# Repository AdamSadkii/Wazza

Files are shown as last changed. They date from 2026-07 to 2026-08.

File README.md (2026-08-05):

# Wazza - Magic in The Air

Wazza is a fully open-source, gesture-controlled AI wand that translates physical hand motions into real-time digital commands. By tracking movement via an internal MPU-6050 6-axis IMU, the onboard ESP32-S3 Mini microcontroller processes gesture vectors, coordinates peripheral systems, and streams telemetry data to an onboard OLED screen alongside audio feedback through an integrated I2S speaker interface.

## Key Features

- 1 x ESP32-S3-MINI-1 Microcontroller (Main Brain)
- 1 x MPU-6050 6-Axis Motion Sensor (IMU)
- 1 x MAX98357A I2S Audio Amplifier & 2W Speaker
- 1 x SPH0645 I2S MEMS Microphone
- 1 x 18650 LiPo Battery Cell
- 1 x TP4056 USB-C Battery Charger Module
- 1 x Tactile Push Button (Momentary switch)
- 1 x WS2812B RGB LED Strip (15-20 LEDs)
- 10 x Resistors (For the required I2C data/clock pull-ups)
- 3 x Electrolytic Capacitors

## How to get the code (not on Vercel)

This is not hosted on Vercel. You grab it from GitHub and run it on your PC.

1. Go to https://github.com/AdamSadkii/Wazza
2. Hit the green Code button
3. Click Download ZIP (or clone it if you use git)
4. Unzip it
5. Open the folder in VS Code / Cursor (or open `Wazza.code-workspace`)

Folders you care about:
- `frontend/` = dashboard
- `backend/` = python server + AI
- `firmware/` = ESP32 code

## Run it on your PC

1. Open a terminal in `backend`
2. Make a venv: `python -m venv .venv`
3. Activate it: `.\.venv\Scripts\Activate.ps1`
4. Install deps: `pip install -r requirements.txt`
5. Run it: `python server.py`
6. Open http://localhost:8000 in your browser

Optional AI:
- set `OPENAI_API_KEY` or run Ollama locally

## Flash the wand

1. Copy `firmware/src/secrets.example.h` to `firmware/src/secrets.h`
2. Put your wifi name/password in there
3. Put your PC IP in `BACKEND_HOST` (port 8765)
4. Open `firmware/` in PlatformIO
5. Build + upload to the ESP32-S3
6. Keep `python server.py` running so the wand can connect

## Schematic








The schematic composes a well organized layout of each system in the device, ranging from power management to the microcontroller itself. This lays the ideal blueprint for the PCB.

The power system (powered by a USB-C component, is the base component of the whole project. A user plugs in a wire in order to actually connect to the code itself, and allow the Ai to run within itself. That way the user can just prompt using the commanded gestures it follows.

## PCB




## Future Enhancements

Potential improvements include on-device machine learning for gesture recognition to reduce API latency, integration with additional sensors like IMUs or proximity detectors, wireless charging capability, and support for custom gesture training. The modular design allows for easy hardware upgrades without redesigning the entire system.

## Files and Documentation

The project includes complete KiCAD schematic files organized by functional module, PCB layout files for fabrication, Arduino firmware source code with gesture templates, and assembly instructions with wiring diagrams. All code is open source and available for modification and redistribution.

## CADDED Module



## Thank you.
A big thanks to Nesh, Keam, and Yahya for being part of the process the whole way. Without them I don't think I would've been able to make it as far.
deduct 2 hrs

## License: MIT

Copyright 2026

Permission is hereby granted, free of charge, to any person obtaining a copy of this software and associated documentation files (the "Software"), to deal in the Software without restriction, including without limitation the rights to use, copy, modify, merge, publish, distribute, sublicense, and/or sell copies of the Software, and to permit persons to whom the Software is furnished to do so, subject to the following conditions:

The above copyright notice and this permission notice shall be included in all copies or substantial portions of the Software.

THE SOFTWARE IS PROVIDED "AS IS", WITHOUT WARRANTY OF ANY KIND, EXPRESS OR IMPLIED, INCLUDING BUT NOT LIMITED TO THE WARRANTIES OF MERCHANTABILITY, FITNESS FOR A PARTICULAR PURPOSE AND NONINFRINGEMENT. IN NO EVENT SHALL THE AUTHORS OR COPYRIGHT HOLDERS BE LIABLE FOR ANY CLAIM, DAMAGES OR OTHER LIABILITY, WHETHER IN AN ACTION OF CONTRACT, TORT OR OTHERWISE, ARISING FROM, OUT OF OR IN CONNECTION WITH THE SOFTWARE OR THE USE OR OTHER DEALINGS IN THE SOFTWARE.

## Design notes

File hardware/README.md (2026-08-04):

# Wazza hardware

| Path | What |
|---|---|
| `kicad/` | KiCad 10 project (schematics + routed PCB) |
| `cad/Wand3.step` | Enclosure CAD (Onshape / Wand3 export) |
| `gerbers/` | Gerber + Excellon drill (+ `wazza_gerbers.zip`) |
| `wiring/` | Schematic PDF + PCB preview / routed renders |
| `WIRING.md` | Net / pin map |
| `ASSEMBLY.md` | Build and assembly steps |

Open `kicad/wazza.kicad_pro` in **KiCad 10**.

## Quick fab

Upload `gerbers/wazza_gerbers.zip` to JLCPCB / PCBWay (or similar).  
Board outline: **155 × 26 mm**, 2-layer.

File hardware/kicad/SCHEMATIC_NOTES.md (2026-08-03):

# Wazza KiCad schematic notes

## What this is
Reconstructed KiCad 10 project from:
- GitHub journal schematic screenshots (Journalphotos.md)
- BOM.md reference designators
- Final hierarchical sheet labels (SDA/SCL/I2S_*/AMP_DIN/MIC_DOUT)

## Open in KiCad
1. Install KiCad 10
2. File -> Open Project -> `hardware/kicad/wazza.kicad_pro`
3. Open `wazza.kicad_sch`

Sheets are wired like the GitHub journal screenshots: orthogonal wires between parts, power ports on pins, global labels at sheet edges.

## Accuracy limits
GitHub does **not** include original `.kicad_sch` sources. Recreation is from screenshots.

Known conflicts between journal revisions:
- Some sheets show I2C on IO21/IO26, others use different GPIOs
- Audio sheet pin annotations disagree across captures
- Early sheets shorted button logic onto SDA (not copied; buttons are separate nets here)
- OLED numbered U15 in one sheet, BOM says U14
- LED rail shown as +5V in one capture, +3V3 in another

This project uses one consolidated MCU map so the hierarchy ERC can resolve:
- IO4 SCL, IO5 SDA
- IO0 BTN_BOOT, IO8 BTN_ACTION
- IO18 LED_DIN
- IO21 I2S_LRCLK, IO26 I2S_BCLK, IO33 AMP_DIN, IO34 MIC_DOUT

Power sheet topology matches the clear USB-C / MCP73831 / battery / AP2112K screenshot.

## Not included
- Full ESP32-S3-MINI-1 pinout (only used pins modeled)
- Exact PCB footprints for every connector
- Layout (`.kicad_pcb`) - ask if you want that next from screenshots

## Sheets
1. `01_power.kicad_sch`
2. `02_mcu.kicad_sch`
3. `03_sensors.kicad_sch`
4. `04_audio.kicad_sch`
5. `05_leds_buttons.kicad_sch`

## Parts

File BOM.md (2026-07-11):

# Wazza BOM

All parts as placed on the KiCad PCB and Schematic.

## Main Components

- **ESP32-S3-MINI-1-N8** (U9): Wi-Fi + BLE MCU module, main brain. Qty 1. [LCSC](https://www.lcsc.com/product-detail/WiFi-Modules_Espressif-Systems-ESP32-S3-MINI-1-N8_C2913206.html) or [Espressif](https://www.espressif.com/en/module/esp32-s3-mini-1-en)
- **MPU-6050** (U13): 6-axis IMU (accelerometer + gyro) for gesture tracking. Qty 1. [Adafruit](https://www.adafruit.com/product/3886)
- **SSD1306 OLED 0.91"** (U14): 128x32 I2C display. Qty 1. [Adafruit](https://www.adafruit.com/product/931)
- **MAX98357A** (U12): I2S 3W Class-D audio amplifier. Qty 1. [Adafruit](https://www.adafruit.com/product/3006)
- **SPH0645LM4H** (MK2/MK3): I2S MEMS microphone, populate one only. Qty 1. [Adafruit](https://www.adafruit.com/product/3421)
- **MCP73831-2** (U1): LiPo charge controller, SOT-23-5. Qty 1. [Microchip](https://www.microchip.com/en-us/product/mcp73831)
- **AP2112K-3.3** (U2): 3.3V 600mA LDO regulator, SOT-23-5. Qty 1. [Diodes Inc](https://www.diodes.com/part/view/AP2112)
- **WS2812B** (D1): Addressable RGB LED, 5050 package. Qty 1. [DigiKey search](https://www.digikey.com/en/products/result?keywords=WS2812B)
- **WS2812B LED strip** (J2): External addressable strip, 15 to 20 LEDs. Qty 1. [Adafruit NeoPixel strip](https://www.adafruit.com/product/1376)
- **Speaker** (LS1): 8 ohm ~1W mini speaker. Qty 1. [Adafruit](https://www.adafruit.com/product/3968)

## Power & Connectors

- **USB-C receptacle** (J1): USB 2.0 16-pin, TYPE-C-31-M-12. Qty 1. [LCSC](https://www.lcsc.com/product-detail/USB-Connectors_Korean-Hroparts-Elec-TYPE-C-31-M-12_C165948.html)
- **JST-EH 2-pin** (BT1): Battery connector, S2B-EH. Qty 1. [DigiKey search](https://www.digikey.com/en/products/result?keywords=S2B-EH)
- **LiPo battery**: 3.7V single cell. Qty 1. [Adafruit 2000mAh](https://www.adafruit.com/product/328)

## Small Parts

- **Tactile switches** (SW2, SW3): Momentary push buttons for action + boot. Qty 2. [Adafruit 20-pack](https://www.adafruit.com/product/367)
- **Resistors** (R1 to R15): 0805 SMD, I2C pull-ups, CC resistors, PROG set, etc. Qty ~10. [DigiKey 0805 resistors](https://www.digikey.com/en/products/filter/chip-resistor-surface-mount/52)
- **Capacitors** (C1 to C5): Decoupling and bulk caps. Qty 5. [DigiKey MLCC](https://www.digikey.com/en/products/filter/ceramic-capacitors/60)

## Notes

- MK2 and MK3 are the same microphone footprint in two positions, populate one only.
- Resistor and capacitor values are in the KiCad schematic; buy a 0805 assortment kit if unsure.
- The bare WS2812B is on-board; J2 is the header for the external strip in the wand shaft.

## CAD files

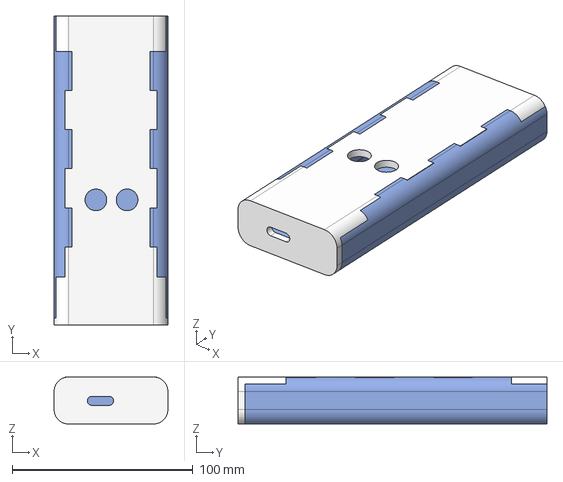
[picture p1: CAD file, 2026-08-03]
hardware/cad/Wand3.step
63.0 x 171.0 x 26.0 mm

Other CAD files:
Wand3 STEP file (1).step

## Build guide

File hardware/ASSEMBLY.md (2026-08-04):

# Wazza assembly instructions

## What you need

- Fabricated PCB from `hardware/gerbers/` (JLCPCB / PCBWay / similar) — use `wazza_gerbers.zip`
- Enclosure STEP: `hardware/cad/Wand3.step`
- Parts from the project BOM / schematic
- USB-C cable, LiPo cell, 8 Ω speaker, NeoPixel strip (optional)

## Board fit

PCB outline is **155 mm × 26 mm** (rounded ends), sized to fit the Wand3 STEP mid-cavity (~51 × 169 mm usable) with wall clearance.  
Confirm fit in CAD before ordering a large panel.

## Before you order (KiCad checklist)

1. Open `kicad/wazza.kicad_pro` and run **DRC**.  
2. Finish remaining ratsnest if any (typically **SDA** and a small **U12-OUTP** stitch).  
3. Refill zones (GND / +3V3 / battery pours).  
4. Re-export Gerbers if you changed copper.

## Solder order

1. SOT-23-5 parts U1 (MCP73831) and U2 (AP2112K-3.3)  
2. 0805 passives (R1–R3, R10, R13–R15, C1, C3, C4)  
3. QFN amp U12 (MAX98357A) and IMU U13  
4. WS2812B (D1)  
5. Buttons SW2 / SW3  
6. USB-C receptacle J1  
7. ESP32-S3-WROOM-1 module U9 (antenna keepout — no metal under antenna)  
8. Headers: battery BT1, OLED U14, speaker LS1, mic MK2, LED strip J2  

## First power-up

1. No battery yet. USB-C only.  
2. Check +3V3 to GND is about 3.3 V.  
3. Confirm no shorts on VBUS / VBAT / +3V3.  
4. Flash firmware (`firmware/`, PlatformIO env `wazza_s3`).  
5. Connect battery only after the 3.3 V rail looks good.

## Enclosure

1. Import `hardware/cad/Wand3.step` into your CAD tool.  
2. Seat PCB in the pocket with USB-C at the handle opening.  
3. Route speaker / mic / LED strip wires toward the tip cavity.  
4. Close shell; keep the antenna end clear of metal.

## Wiring reference

- Pin map: `hardware/WIRING.md`  
- Schematic PDF: `hardware/wiring/wazza_schematic.pdf`  
- PCB renders: `hardware/wiring/pcb_preview.png`, `pcb_routed.png`

## Accuracy note

Journal PCB screenshots were the visual reference; this KiCad board recreates that placement and STEP fit, then autoroutes copper. Treat the first fab spin as a prototype and verify DRC in KiCad first.

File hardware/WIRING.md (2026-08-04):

# Wazza hardware wiring

Source of truth for nets: KiCad schematics in `hardware/kicad/`.
PDF export: `hardware/wiring/wazza_schematic.pdf`.

## Consolidated MCU map (matches firmware)

| Net | ESP32-S3 pin | Goes to |
|-----|---|---|
| SCL | IO4 | MPU-6050, OLED, 4.7k pull-up to +3V3 |
| SDA | IO5 | MPU-6050, OLED, 4.7k pull-up to +3V3 |
| BTN_BOOT | IO0 | SW3 to GND, 10k pull-up to +3V3 |
| BTN_ACTION | IO8 | SW2 to GND, 10k pull-up to +3V3 |
| LED_DIN | IO18 | WS2812B DIN, then DOUT to strip header J2 |
| I2S_LRCLK | IO21 | MAX98357A LRCLK, mic WS |
| I2S_BCLK | IO26 | MAX98357A BCLK, mic BCLK |
| AMP_DIN | IO33 | MAX98357A DIN |
| MIC_DOUT | IO34 | SPH0645 DATA |
| +3V3 / GND | module rails | all ICs |

## Power path

USB-C VBUS -> MCP73831 -> VBAT / LiPo -> AP2112K-3.3 -> +3V3  
CC1/CC2 each have 5.1k to GND. PROG uses 2k to GND.

## Sheet map

1. `01_power` – USB-C, charger, battery, 3.3V LDO  
2. `02_mcu` – ESP32-S3 module + GPIO globals  
3. `03_sensors` – MPU-6050 + OLED + I2C pull-ups  
4. `04_audio` – MAX98357A + mic + speaker  
5. `05_leds_buttons` – WS2812B, strip header, buttons  

## Fabrication outputs

Gerbers + drill: `hardware/gerbers/` (zip: `wazza_gerbers.zip`)  
PCB preview: `hardware/wiring/pcb_preview.png`  
Routed render: `hardware/wiring/pcb_routed.png`

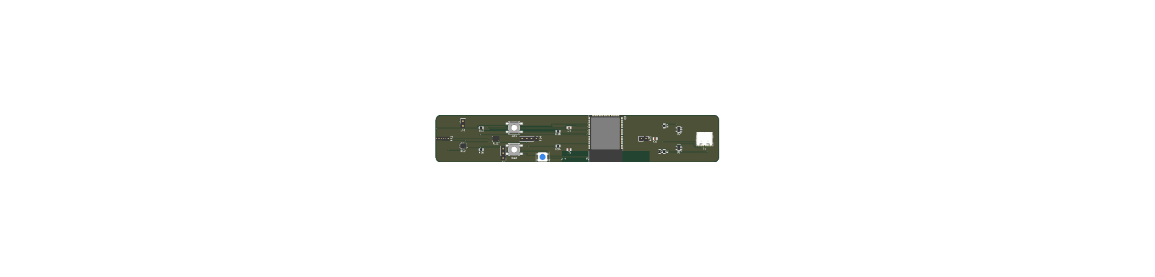
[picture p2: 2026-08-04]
hardware/wiring/pcb_routed.png

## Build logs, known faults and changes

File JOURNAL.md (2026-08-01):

# JOURNAL

## Schematic Complete - Day 6/28/26 (5h58min)

### Overview
Finally finished the schematic. Coming into this schematic, I knew I wanted to focus on one thing: the microcontroller as the main component. However, in hopes of organization, I thought otherwise and considered splitting things up.

### Design Decisions

At first, I originally wanted to split my schematic into different pages, each serving their own purpose. I planned one page for the sensor interface, another for the audio interface, and so on and so forth. However, due to redundancy (I tried to add a connections page combining everything) and time constraints, I realized the easier pathway led to one single schematic instead.

### Architecture

The basis of my schematic focuses on, as said before, my microcontroller: the ESP32. The ESP32 served as the central component of my project, with everything else orbiting around it:

* **ESP32**: The brain of the operation, handling all processing and coordination
* **OLED Display**: Provides the user with basic info and feedback
* **MPU-6050**: Tracks the user's gestures and movements (literally one of the most important parts of my wand LOL)
* **Supporting Components**: Battery management, audio I/O, LED control, all centralized around the microcontroller

### What I Learned

Keeping everything on a single page actually made more sense than I initially thought. The redundancy of multiple connection pages would have just added complexity without clarity. Sometimes simpler is better, and this schematic proves that point.

### Next Steps

Tomorrow, I will get to the PCB and hopefully get most of it done. Although it's an impending doom, I am really excited to work on that aspect of my project. The schematic is solid, so the layout should flow naturally from here.

### Reflection

This feels like a major milestone. The schematic is the blueprint for everything that comes next. Seeing all the connections laid out clearly gives me confidence that the hardware design is sound. Time to bring it to life on the PCB.

---

## Organizing PCB - Day 6/29/26 (Hour 1) **[LAPSED DAY]**

I am organizing the PCB. Currently splitting each component on its own but we're figuring it out. Even though the components are a little hard to figure out, it's totally okay. 



---

## Schematic Fix - Day 6/29/26 (Hours 2-3) **[LAPSED DAY]**

I discovered a major error on the PCB layout where resistors R4 and R5 were both connected directly to the 3.3V line, which would have broken the communication loop. After two hours of troubleshooting, I corrected the wiring paths and utilized several pins that were previously ignored. This process exposed a widespread series of errors throughout the schematic, requiring another two hours of focused adjustments. While the rework was incredibly tedious, tracking down and correcting those design flaws was deeply rewarding.





---

## Journal Day 6/29/26 - PCB Almost Done? (Hours: 3) **[LAPSED DAY]**

PCB Layout Started - Day 6/30/26 **[LAPSED DAY]**

### Overview

Today was incredibly productive yet absolutely exhausting. I took the massive leap into creating my first-ever physical PCB layout. Moving from the abstract schematic canvas to actual component footprints makes the wand feel real, though it definitely brought some brutal troubleshooting with it.

### Design Decisions & Troubleshooting

I hit a major roadblock early on regarding the OLED screen and the IMU pull-up resistors. During my initial layout check, I realized my wiring accidentally tied both sides of $R4$ and $R5$ directly to the +3.3V line, completely missing the actual SCL and SDA lines. Instead of moving forward with a broken bus, I paused and forced myself to rewire those schematic components properly. It took a couple of hours of careful tracing, but I finally re-run the check successfully. Once the schematic was cleared, I imported it into the PCB editor and successfully modeled the initial physical flow of the wand stretching all the way from the USB-C port to the OLED screen placement.

### Architecture

As the layout began coming together, the physical constraints forced me to re-evaluate my component choices:

* **ESP32 Module**: Looking at the footprint placement, I realized I might have utilized the wrong specific module variant. Thankfully, it's not a catastrophic fix; I just need to swap the symbol/footprint and re-designate the pins to match my existing wiring routing.
* **Net Labels**: Moving forward, I need to heavily integrate net labels rather than drawing raw local wires. It will make updating the schematic and updating the PCB track layout infinitely smoother.

### What I Learned

Catching a massive I2C pull-up mistake now instead of after fabrication taught me why electrical checks are so critical. A few hours of frustration today saved weeks of waiting on a broken, un-fixable board later.

### Next Steps

Tomorrow is all about fixing that ESP32 module variant, cleaning up the routing, and finalizing the board outline. There is still a bit of uncertainty about the tight layout, but the goal is to get the CAD fully submitted so we can ship the design files out for manufacturing. Job's not finished; let's get this accepted.




---

## Schematic Rewire WE ALMOST DONE - Day 6/30/26 (Hours 1-2) **[LAPSED DAY]**

Decided to rewire my schematic as I realized I was using the Chip version of the ESP32-S3 and not the actual module version (I chose the ESP32-S3 Mini). Both my sensor interface and power management is done. 




---

## Schematic Rewire So close - Day 6/30/26 (Hours 3-4) **[LAPSED DAY]**

I decided for a neater version so I resorted to different page sheets and made it simpler. This solved my rewiring issue entirely and made it much more simpler. Additionally, I resorted to the ESP32-S3 Mini and was able to complete a successful rewire towards the microcontroller connecting everything at once. 





---

## Schematic Rewire - Day 6/30/26 (Hours 4-5) **[LAPSED DAY]**

To end the Schematic Rewire (finally..) I finished my OLED and Audio Interface, two important components connecting to my ESP32. The OLED will display info and will later be programmed to do so, meanwhile the Audio Interface will do the same in an audio format. 




---

## Day 6/30/26 (4hrs 48 min) **[LAPSED DAY]**

### Devlog â€“ June 30, 2026

**Focus:** Complete Schematic Overhaul, Hierarchical Sheets, & Peripheral Integration

Massive milestone hit today. Realized a fundamental mismatch in the central microcontroller component selection and completely overhauled the schematic architecture to transition from a messy, single-page layout to a clean, production-ready multi-sheet design.

#### Accomplishments:

* **Microcontroller Core Correction (Hours 1â€“2):**
  * Identified a critical error: the schematic originally used the raw ESP32-S3 IC (chip-down) instead of the actual integrated module (**ESP32-S3-MINI-1**).
  * Swapped out the component block, completely saving the project from massive PCB routing headaches later, as the mini module integrates the flash, RAM, and antenna circuitry automatically.
  * Verified that the completed Sensor Interface and Power Management blocks survived the migration.

* **Hierarchical Page Sheet Migration (Hours 3â€“4):**
  * To solve the escalating "spaghetti wire" mess, abandoned the single-page layout and refactored the entire project into individual hierarchical page sheets.
  * This modular approach completely cleared up the wiring bottlenecks and allowed for a seamless, successful master rewire back to the new ESP32-S3 Mini block using clean global labels.

* **OLED & Audio Interface Integration (Hours 4â€“5):**
  * Finalized the schematic wiring for the dual feedback systems: the visual **OLED Display** block and the **I2S Audio Interface** block.
  * Mapped out the display paths to handle future telemetry data readouts and stabilized the I2S audio channels (microphone input and amplifier output) to provide clean audio feedback down the line.

#### Project Status 6/30/26:

The schematic is officially **100% complete** and fully modularized. Every subsystem, Power, Sensors, OLED, Audio, and LEDs, is cleanly tied back to the ESP32-S3 Mini. Ready to lock it in and move to footprints.




---

## PCB Organized - Time to Reroute! 7/3/26: (1-2 Hours)

The PCB is finally organized, it's time to reroute and make sure the chip is well done and suited. CADDING IS VERY SOON.



---

## Routing... 7/3/26 (2-3 hour)

It's taking a while but we're getting there. I am currently routing everything, PCB will be done by tonight.




---

## Project Development Log: Routing Phase Completion Date: 7/4/26 (5 hours)

I have successfully completed the routing phase for the entire printed circuit board layout. Managing the trace routing presented several structural challenges, particularly regarding the speaker interface strategy and component placement constraints. 

Despite these spatial complexities, all nets have been fully routed, and the connection matrix is complete. The board layout is clean, and the netlist is fully satisfied with zero remaining unrouted connections. The immediate next steps include performing a comprehensive Design Rule Check to verify electrical clearances, optimizing the silkscreen component designators for legibility, and generating the final copper ground pours. 

Once these verification steps are complete, the project will move into the manufacturing file generation phase.



---

## Routing Complete! 7/7 (Hours 1-2) 

Completed routing after reassembling 3 days ago. I was able to reroute everything with the correct net labels finally.





ENJOY WE MAKING HOLES NOW.

---

## Holes Complete, onto CADDING! 7/7 (Hours 2-3)

Holes are officially done, time to move straight onto CADDING.



---

## CADDING... 7/7 (Hour 3)

WE are currently sketching and beginning our first steps into cadding the wand. Lets go.

 

---

## EVERYTHING DONE LETS GOOOOOOOOOO OMG 7/7 (Hours 3-4)

We finished the PCB Routing, we finished the designs, we finished the cadding. WE DID IT (lebron quote.. or jayson tatum? idk but we are completely done). 



---

## Day 7/7/26 (Hours 3-4)

### Devlog â€“ July 7, 2026

**Focus:** Final Routing Validation, Board Mounting Holes, & Structural CAD Completion

Massive milestone hit today. Everything is officially wrapped up from the physical board connections to the outer wand enclosure design. The full system is fully modeled and ready for production file generation.

#### Accomplishments:

* **PCB Routing Validation:**
  * Cleaned up and verified 100% of the trace connections across the board layout, matching everything perfectly with the new net labels on the ESP32-S3 Mini.
  * Completed the full connection matrix with zero remaining unrouted nets or trace bottlenecks.

* **Physical Mounting Holes:**
  * Added the structural mounting drill holes directly onto the finalized PCB outline.
  * Verified all hardware component clearances around the holes to ensure secure physical assembly inside the wand body without risking any trace shorts.

* **3D CAD Assembly:**
  * Transitioned straight from the completed board layout into sketching and cadding the final physical wand body.
  * Successfully matched all component layout configurations, display cutouts, and physical boundary constraints to complete the initial enclosure assembly sketch.

## Day 7/31/26 (Hours 16-17) (LAPSED ON TEAANHACKCLUB@gmail.com USER)

Currently lapsing my email, Currently working on the server.py to handle all of the Wand's messages to the user.



#### Project Status 7/31/26:

The physical layout and hardware configuration phase is **100% complete**. The schematic wiring sheets, PCB routing networks, structural mounting layouts, and external CAD design frames are all fully locked in. Ready to export manufacturing assets and ship it.

---

### Note on Lapsed Days

Days 6/29/26 and 6/30/26 were lapsed for a combined 6hr 17min. These entries are logged above as they were originally recorded. These hours were tracked on my other user --> (teaangoat@gmail.com) the rest of the Hackatime hours are tracked on (teaanhackclub@gmail.com) combining together to make up the total 20 hrs expected by the July 31st deadline.

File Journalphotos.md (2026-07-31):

## Hour 1 6/29/2026


## Hours 2-3 6/29/2026






## Hours 1-2 6/30/2026



## Hours 3-4 6/30/2026




## Hours 4-5 6/30/2026



## Hours 1-2 7/3/2026


## Hours 2-3 7/3/2026



## Hours 1-2 7/7/2026




## Hours 2-3 7/7/2026



## Hours 3-4 7/7/2026


## Hours 16-17 7/31/2026


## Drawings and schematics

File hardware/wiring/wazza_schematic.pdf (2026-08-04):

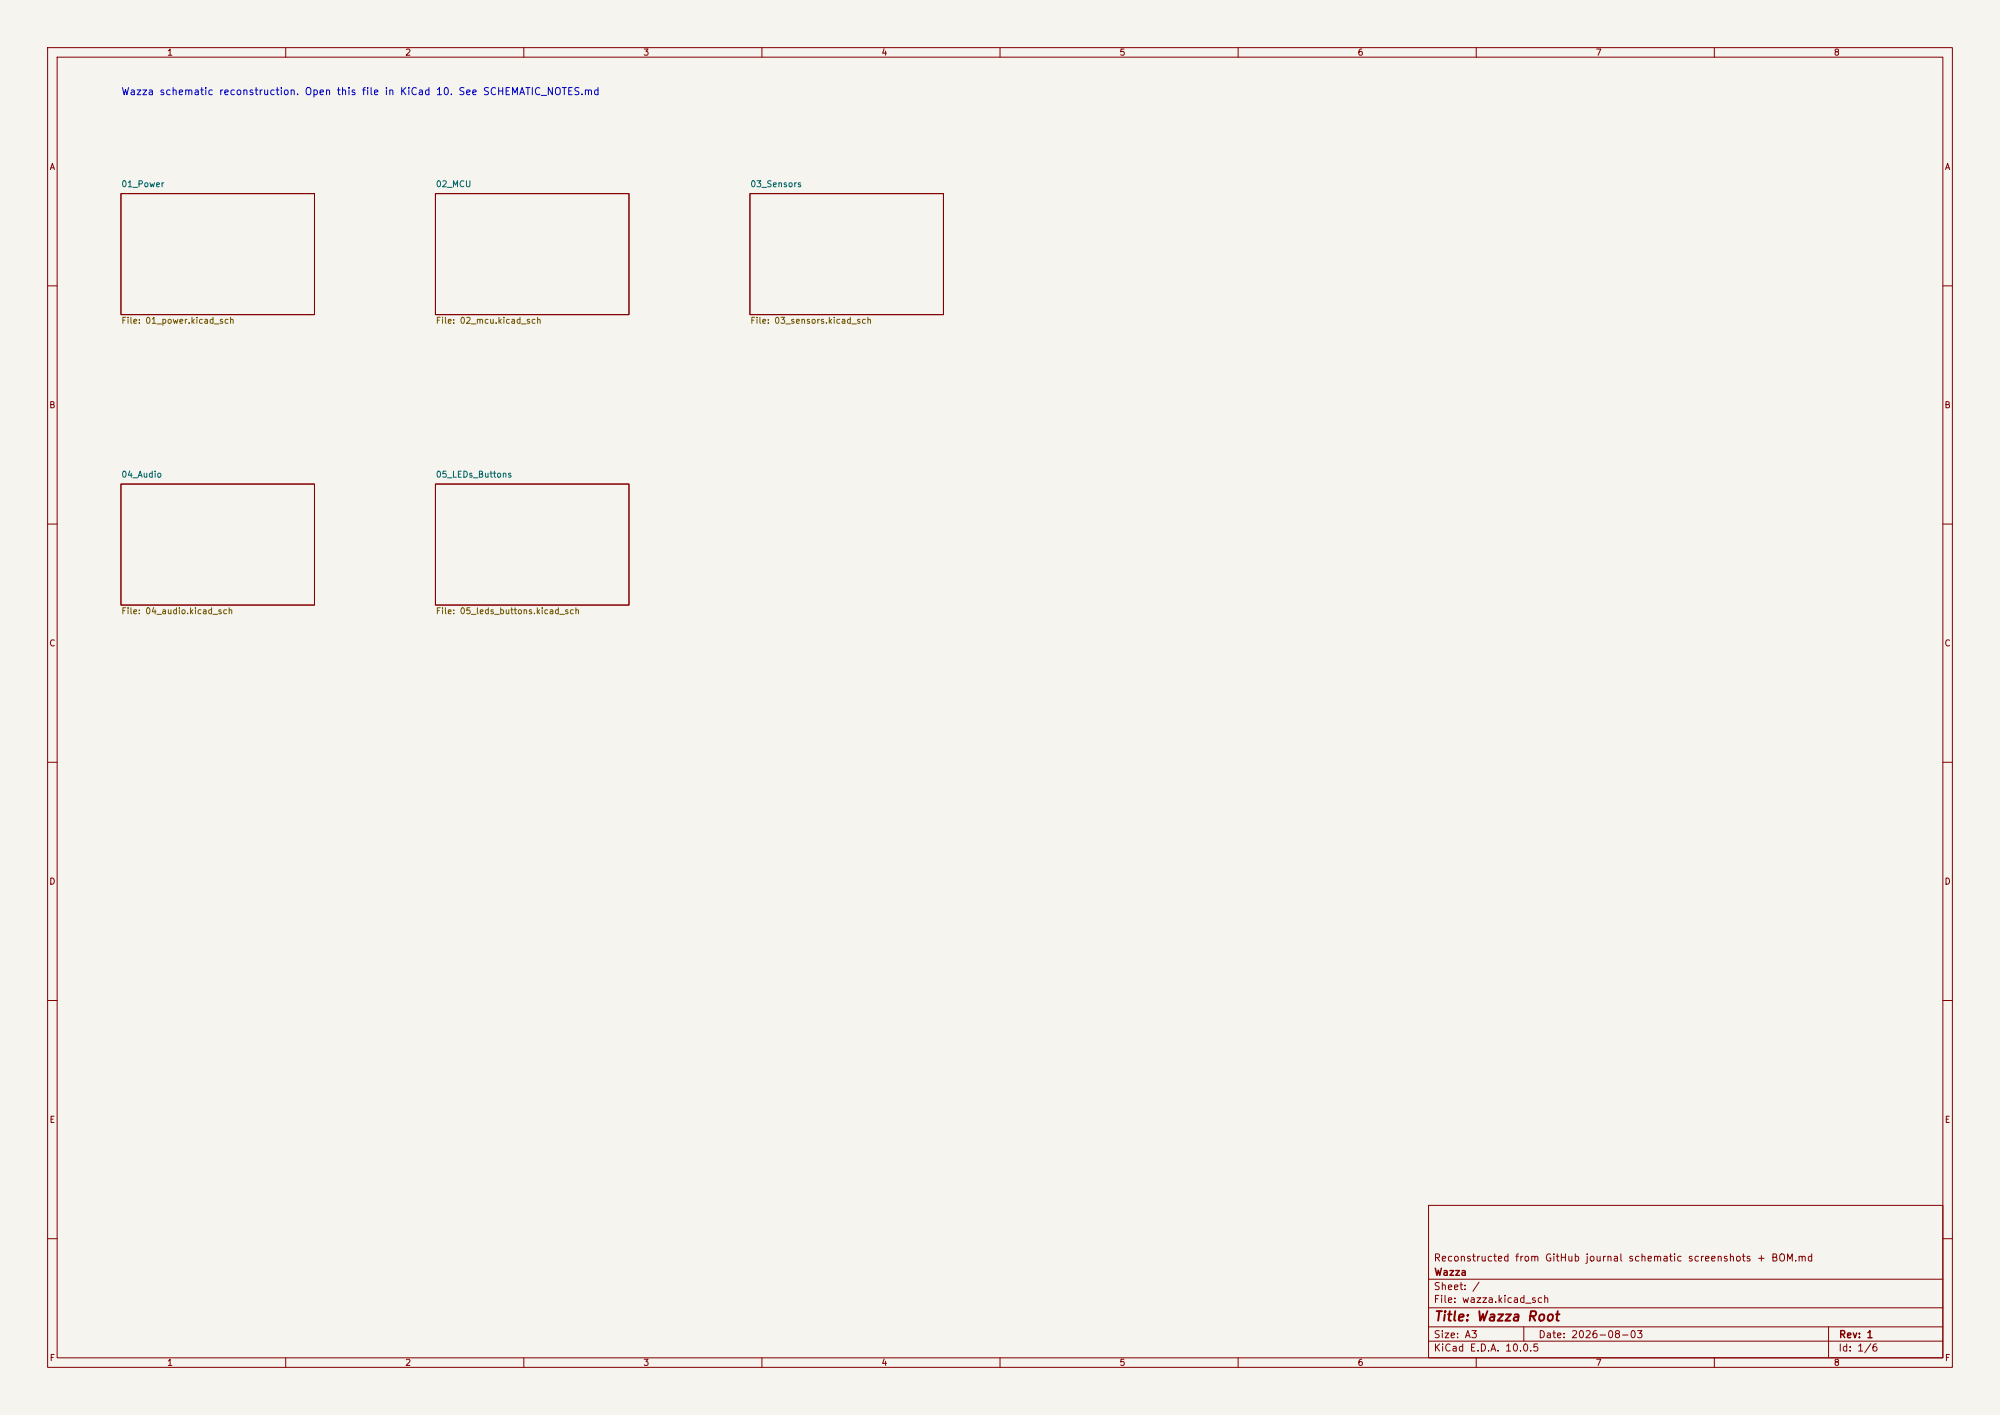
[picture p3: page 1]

File: 02_mcu.kicad_sch Wazza schematic reconstruction. Open this file in KiCad 10. See SCHEMATIC_NOTES.md

Reconstructed from GitHub journal schematic screenshots + BOM.md
Wazza
Sheet: /
File: wazza.kicad_sch
Title: Wazza Root

Size: A3 | Rev: 1 | F Date: 2026-08-03
KiCad E.D.A. 10.0.5 | Id: 1/6

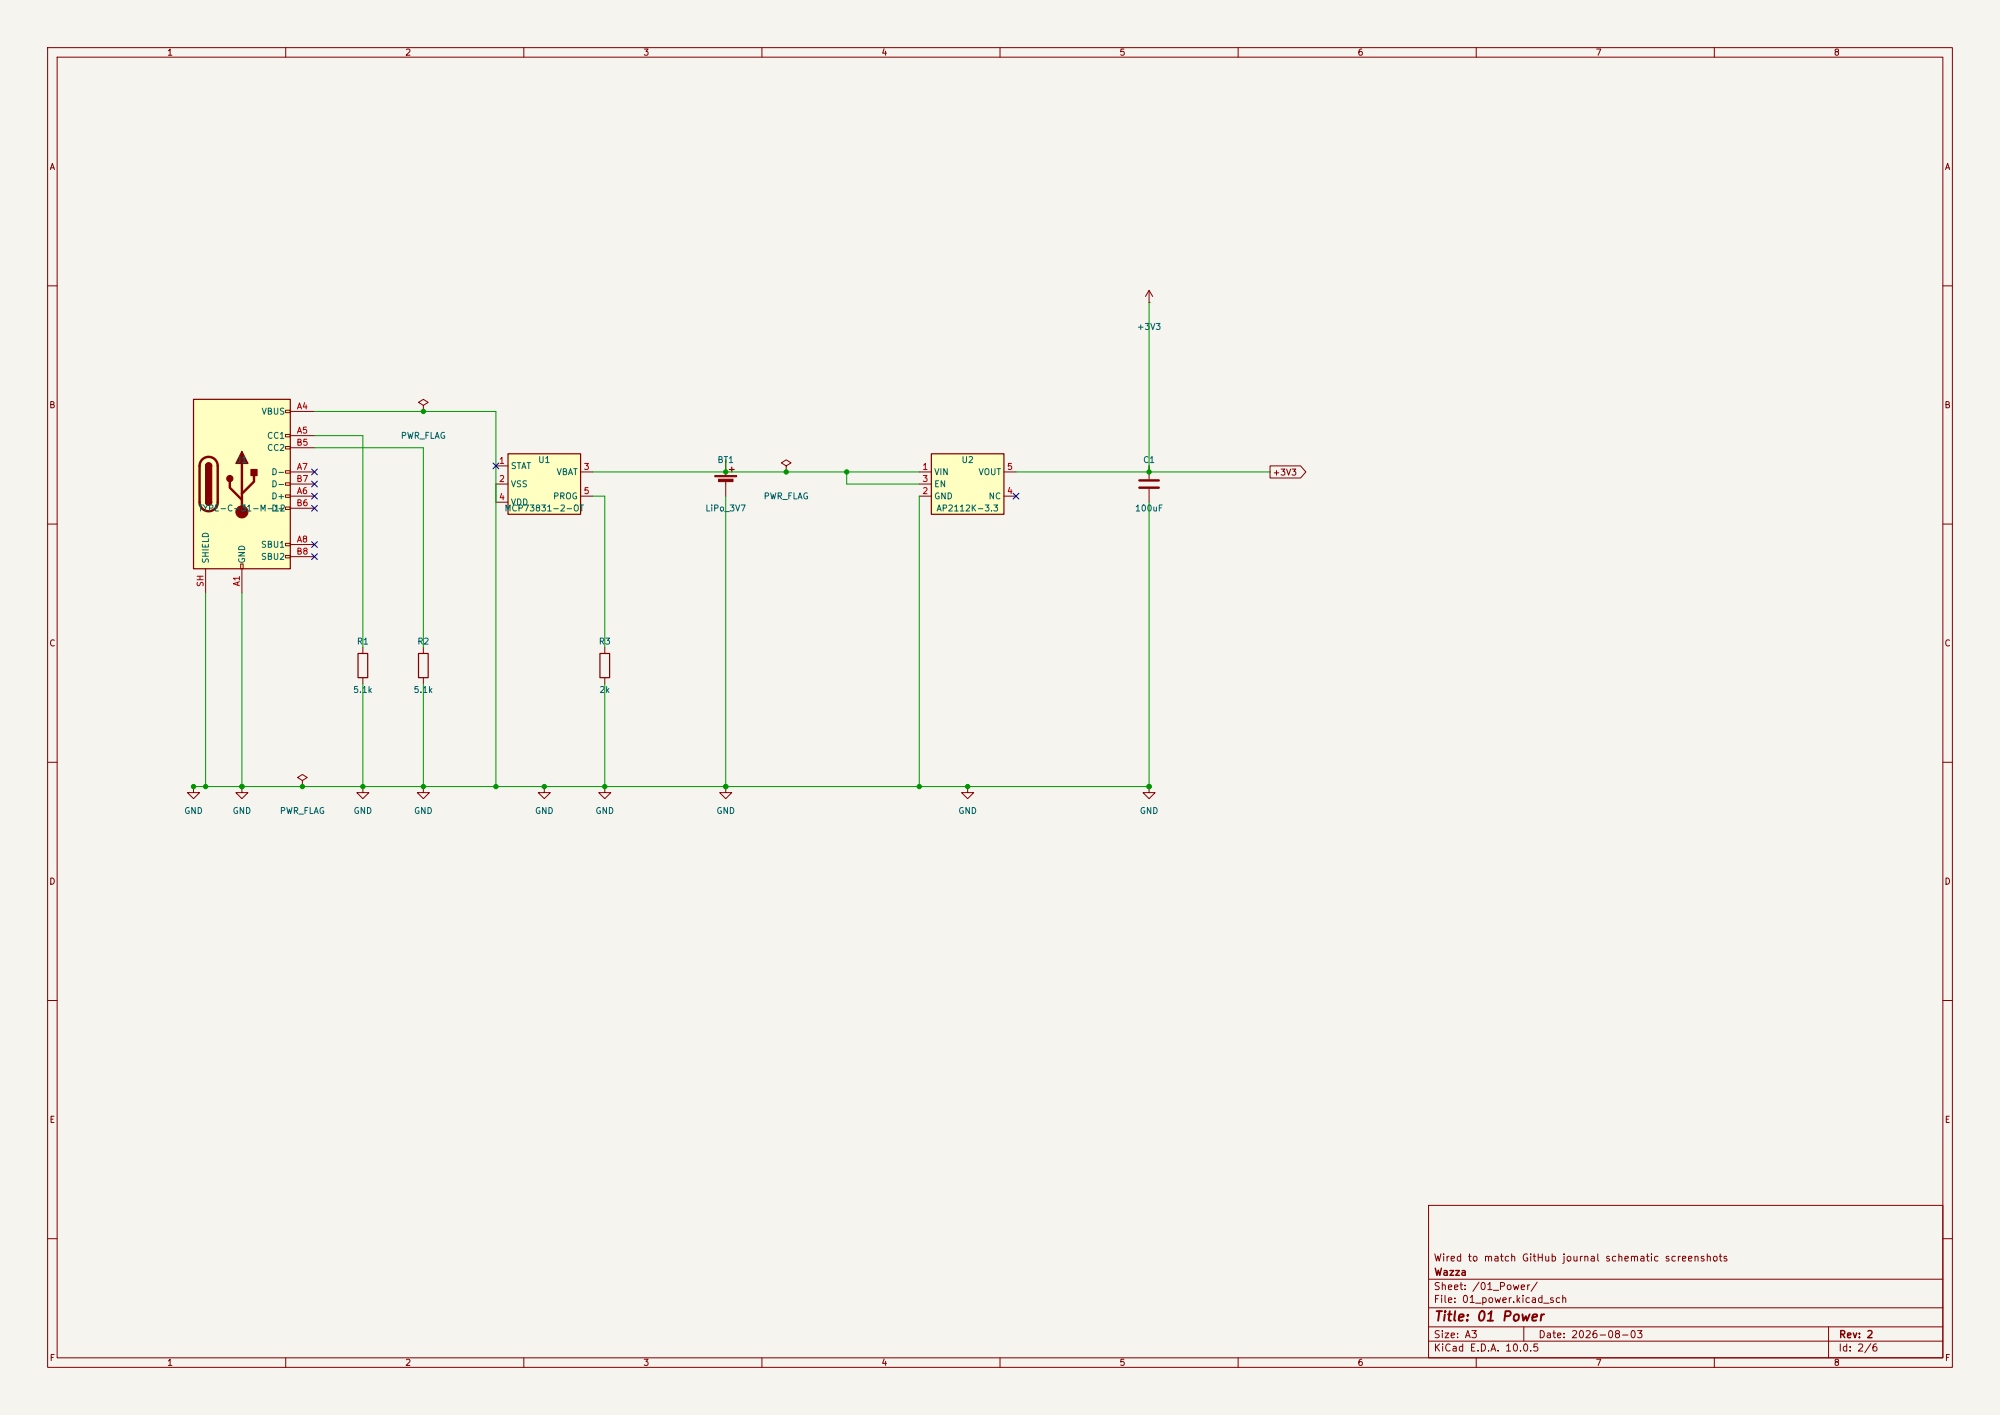
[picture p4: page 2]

Wired to match GitHub journal schematic screenshots
Wazza
Sheet: /01_Power/
File: 01_power.kicad_sch
Title: 01 Power

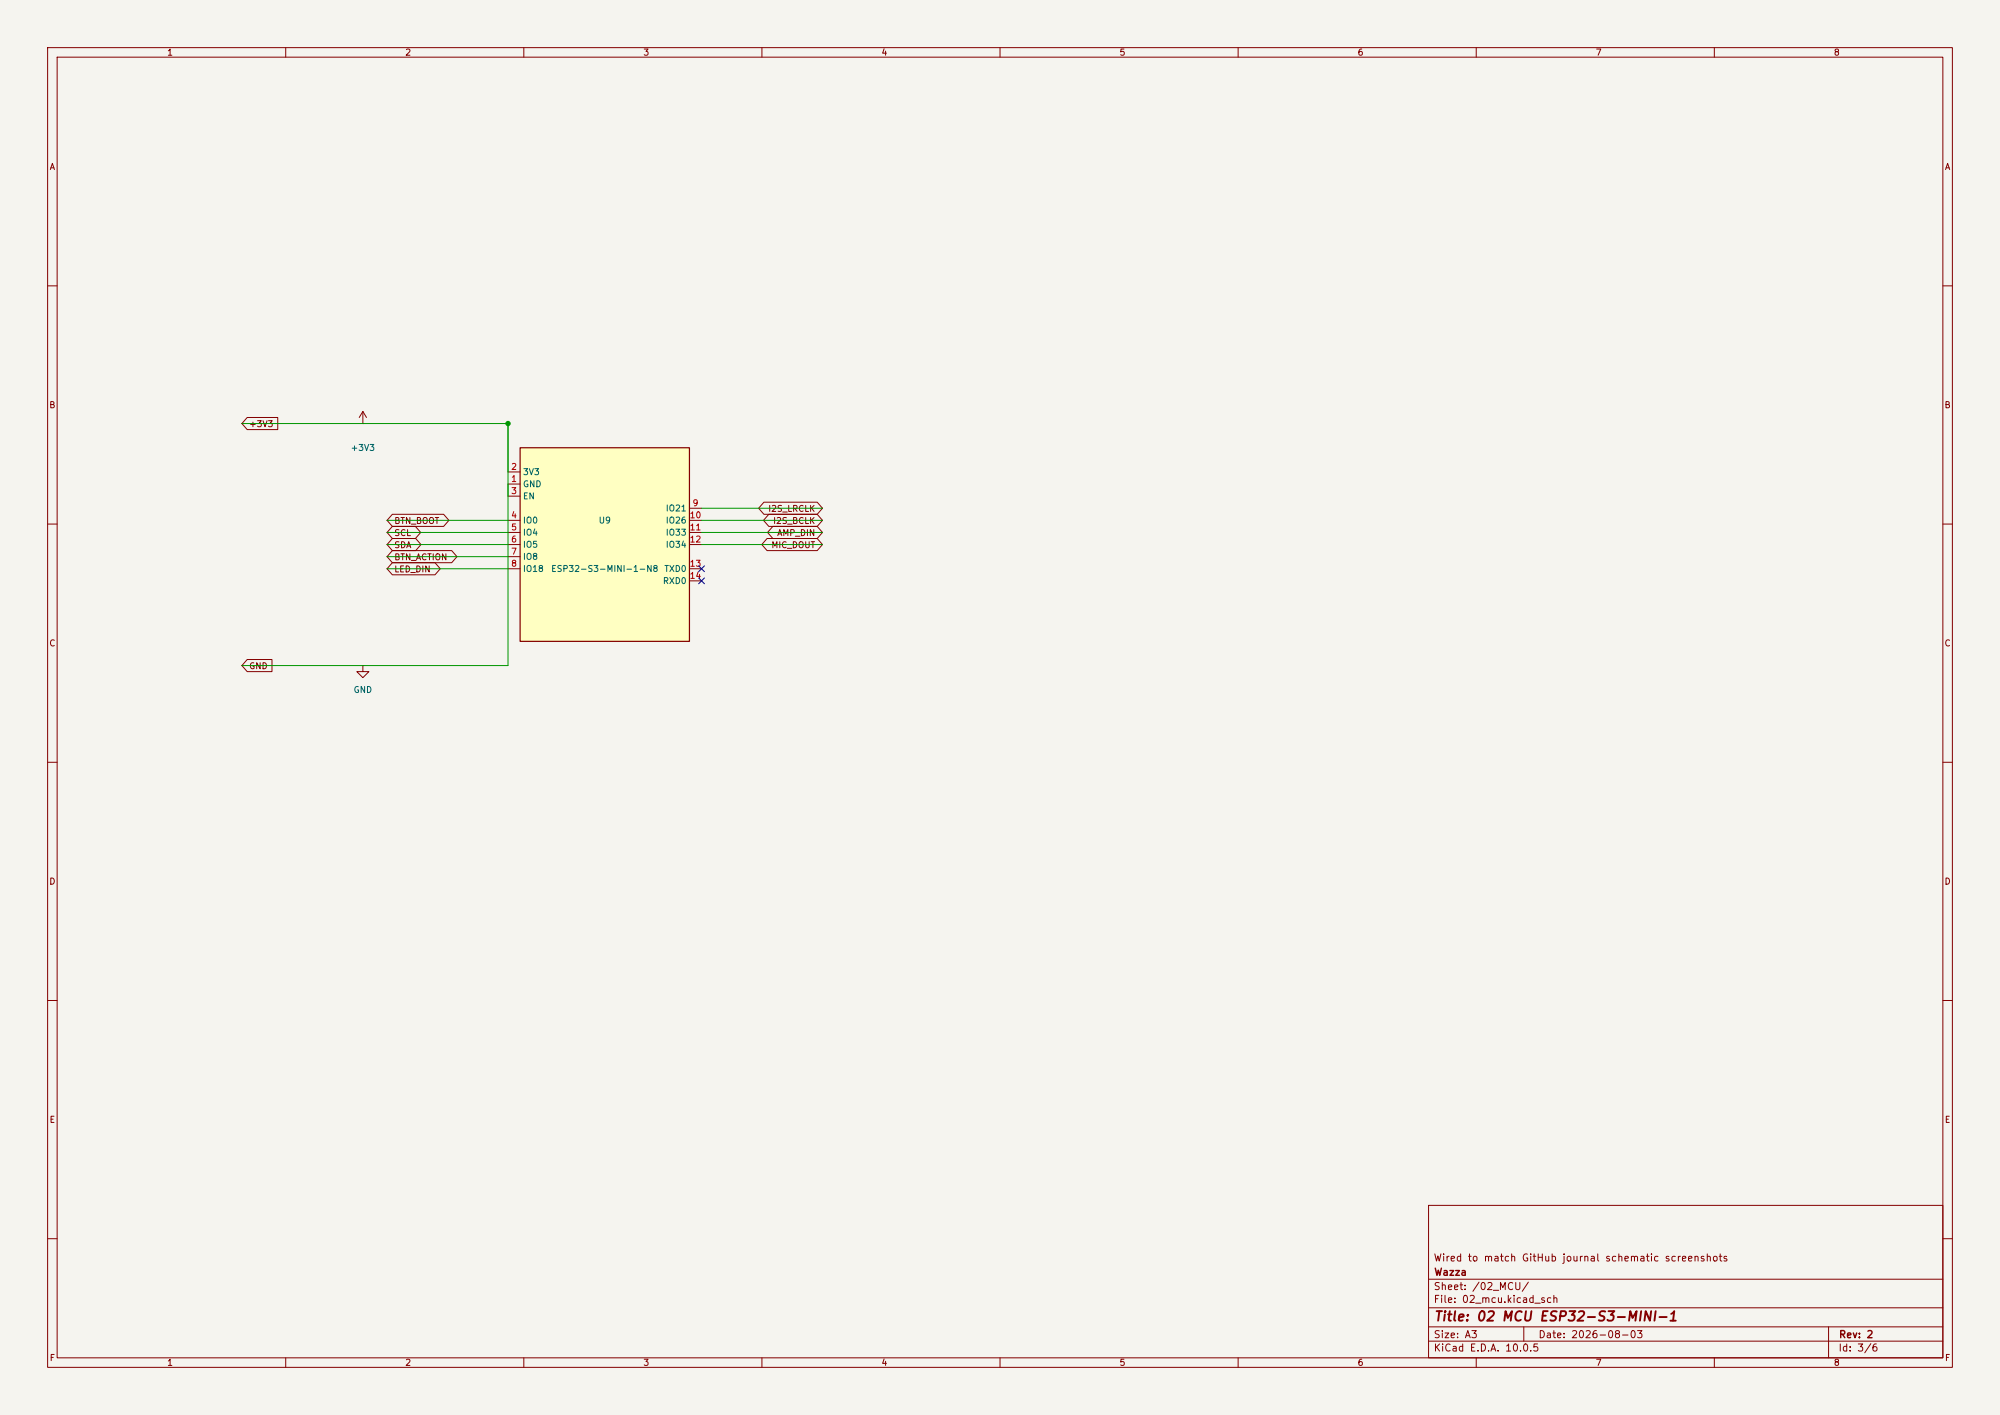
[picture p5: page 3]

Wired to match GitHub journal schematic screenshots
Wazza
Sheet: /02_MCU/
File: 02_mcu.kicad_sch
Title: 02 MCU ESP32-S3-MINI-1

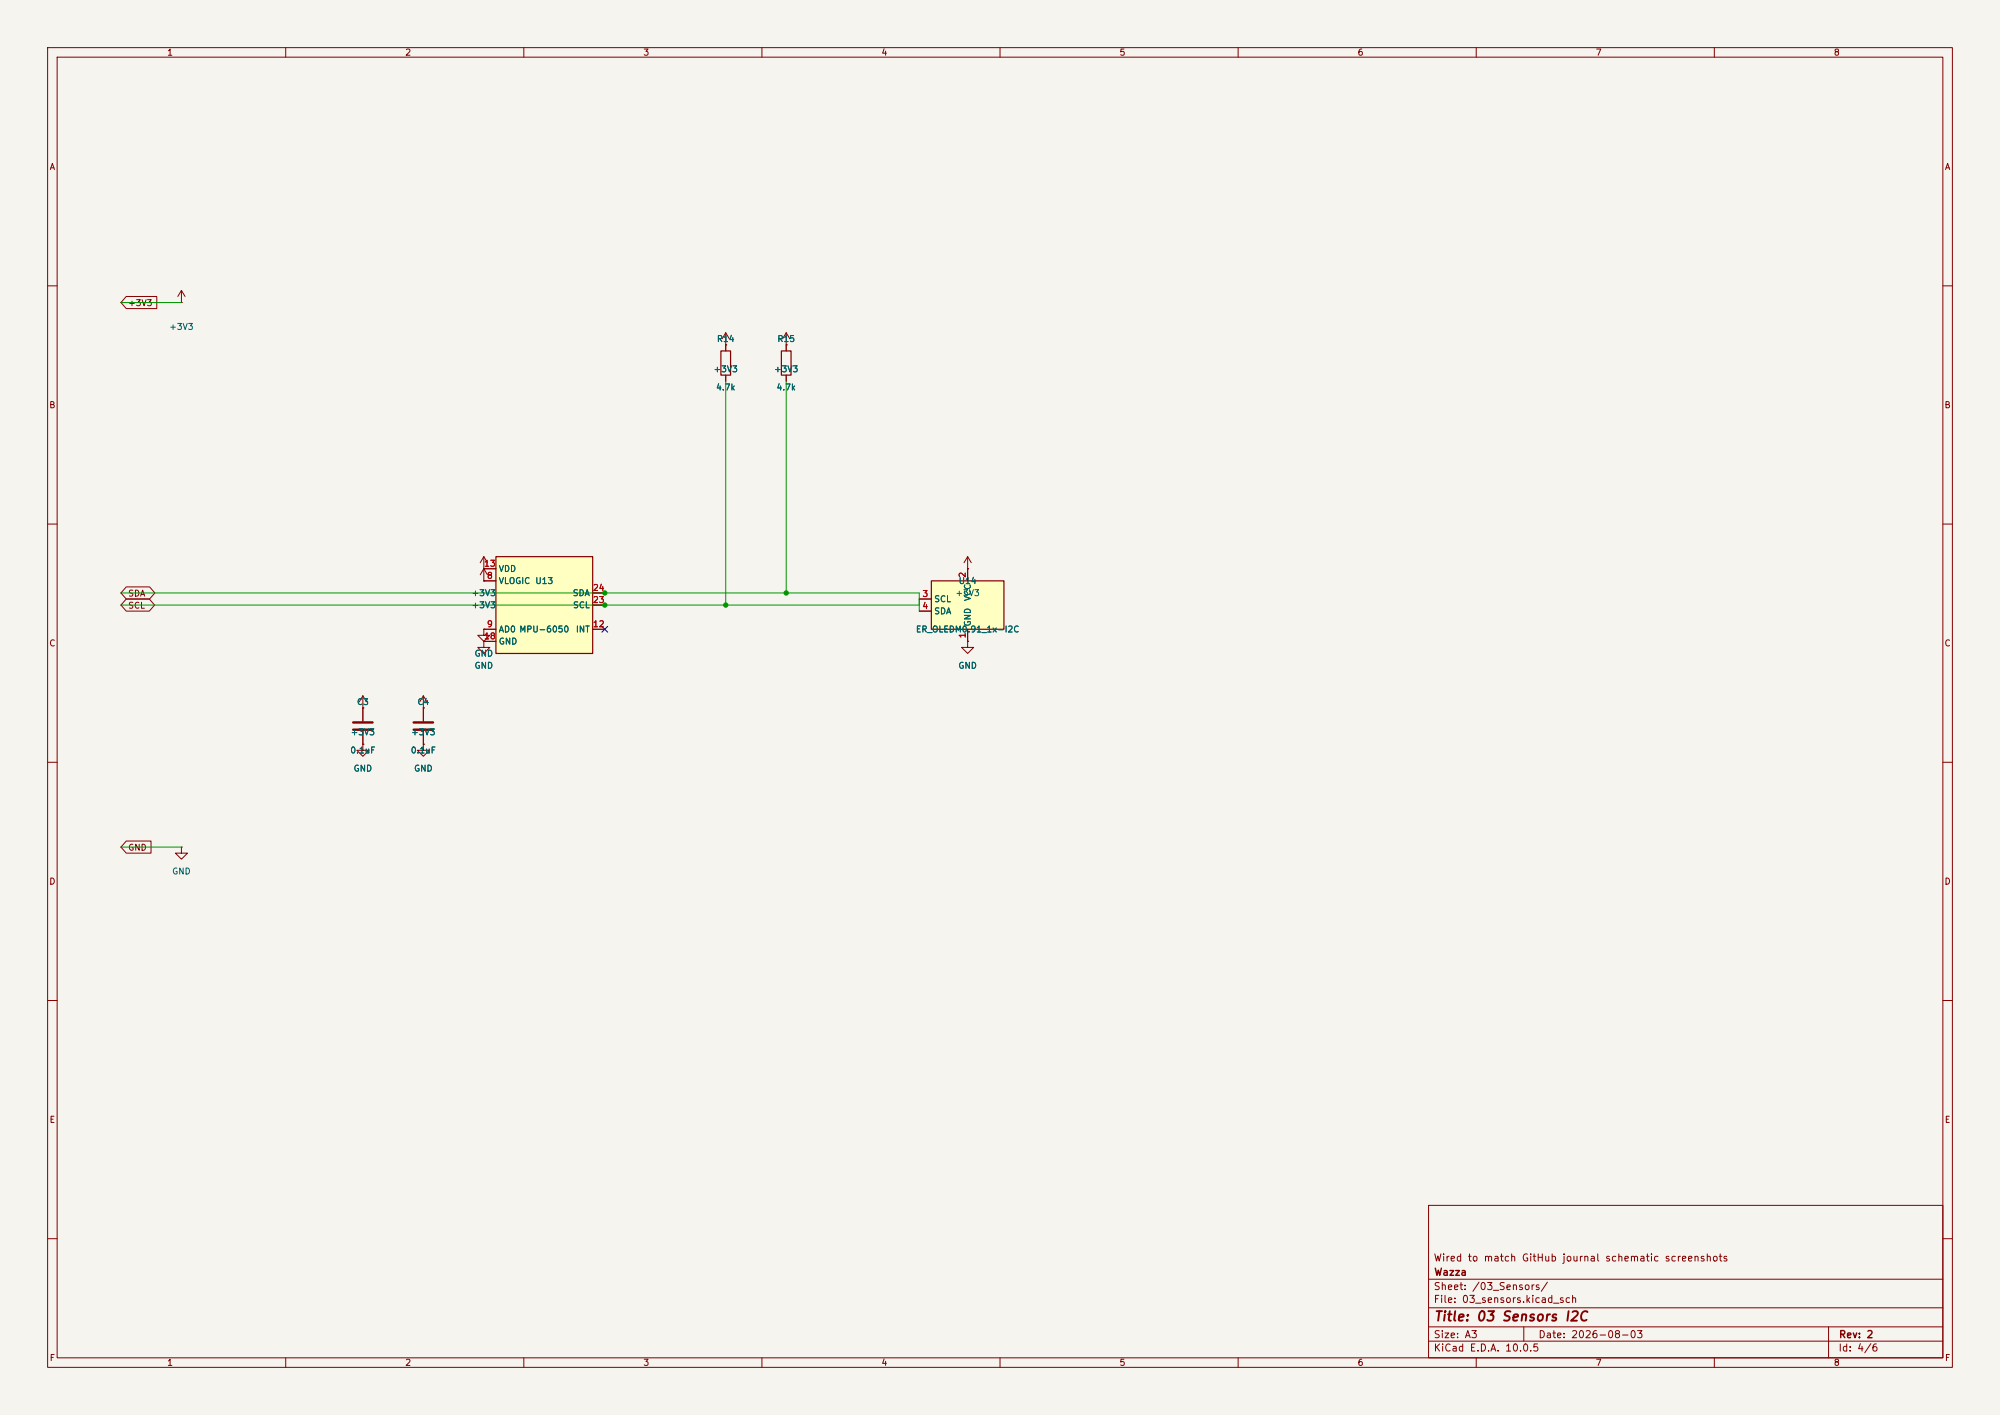
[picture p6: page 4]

Wired to match GitHub journal schematic screenshots
Wazza
Sheet: /03_Sensors/
File: 03_sensors.kicad_sch
Title: 03 Sensors I2C

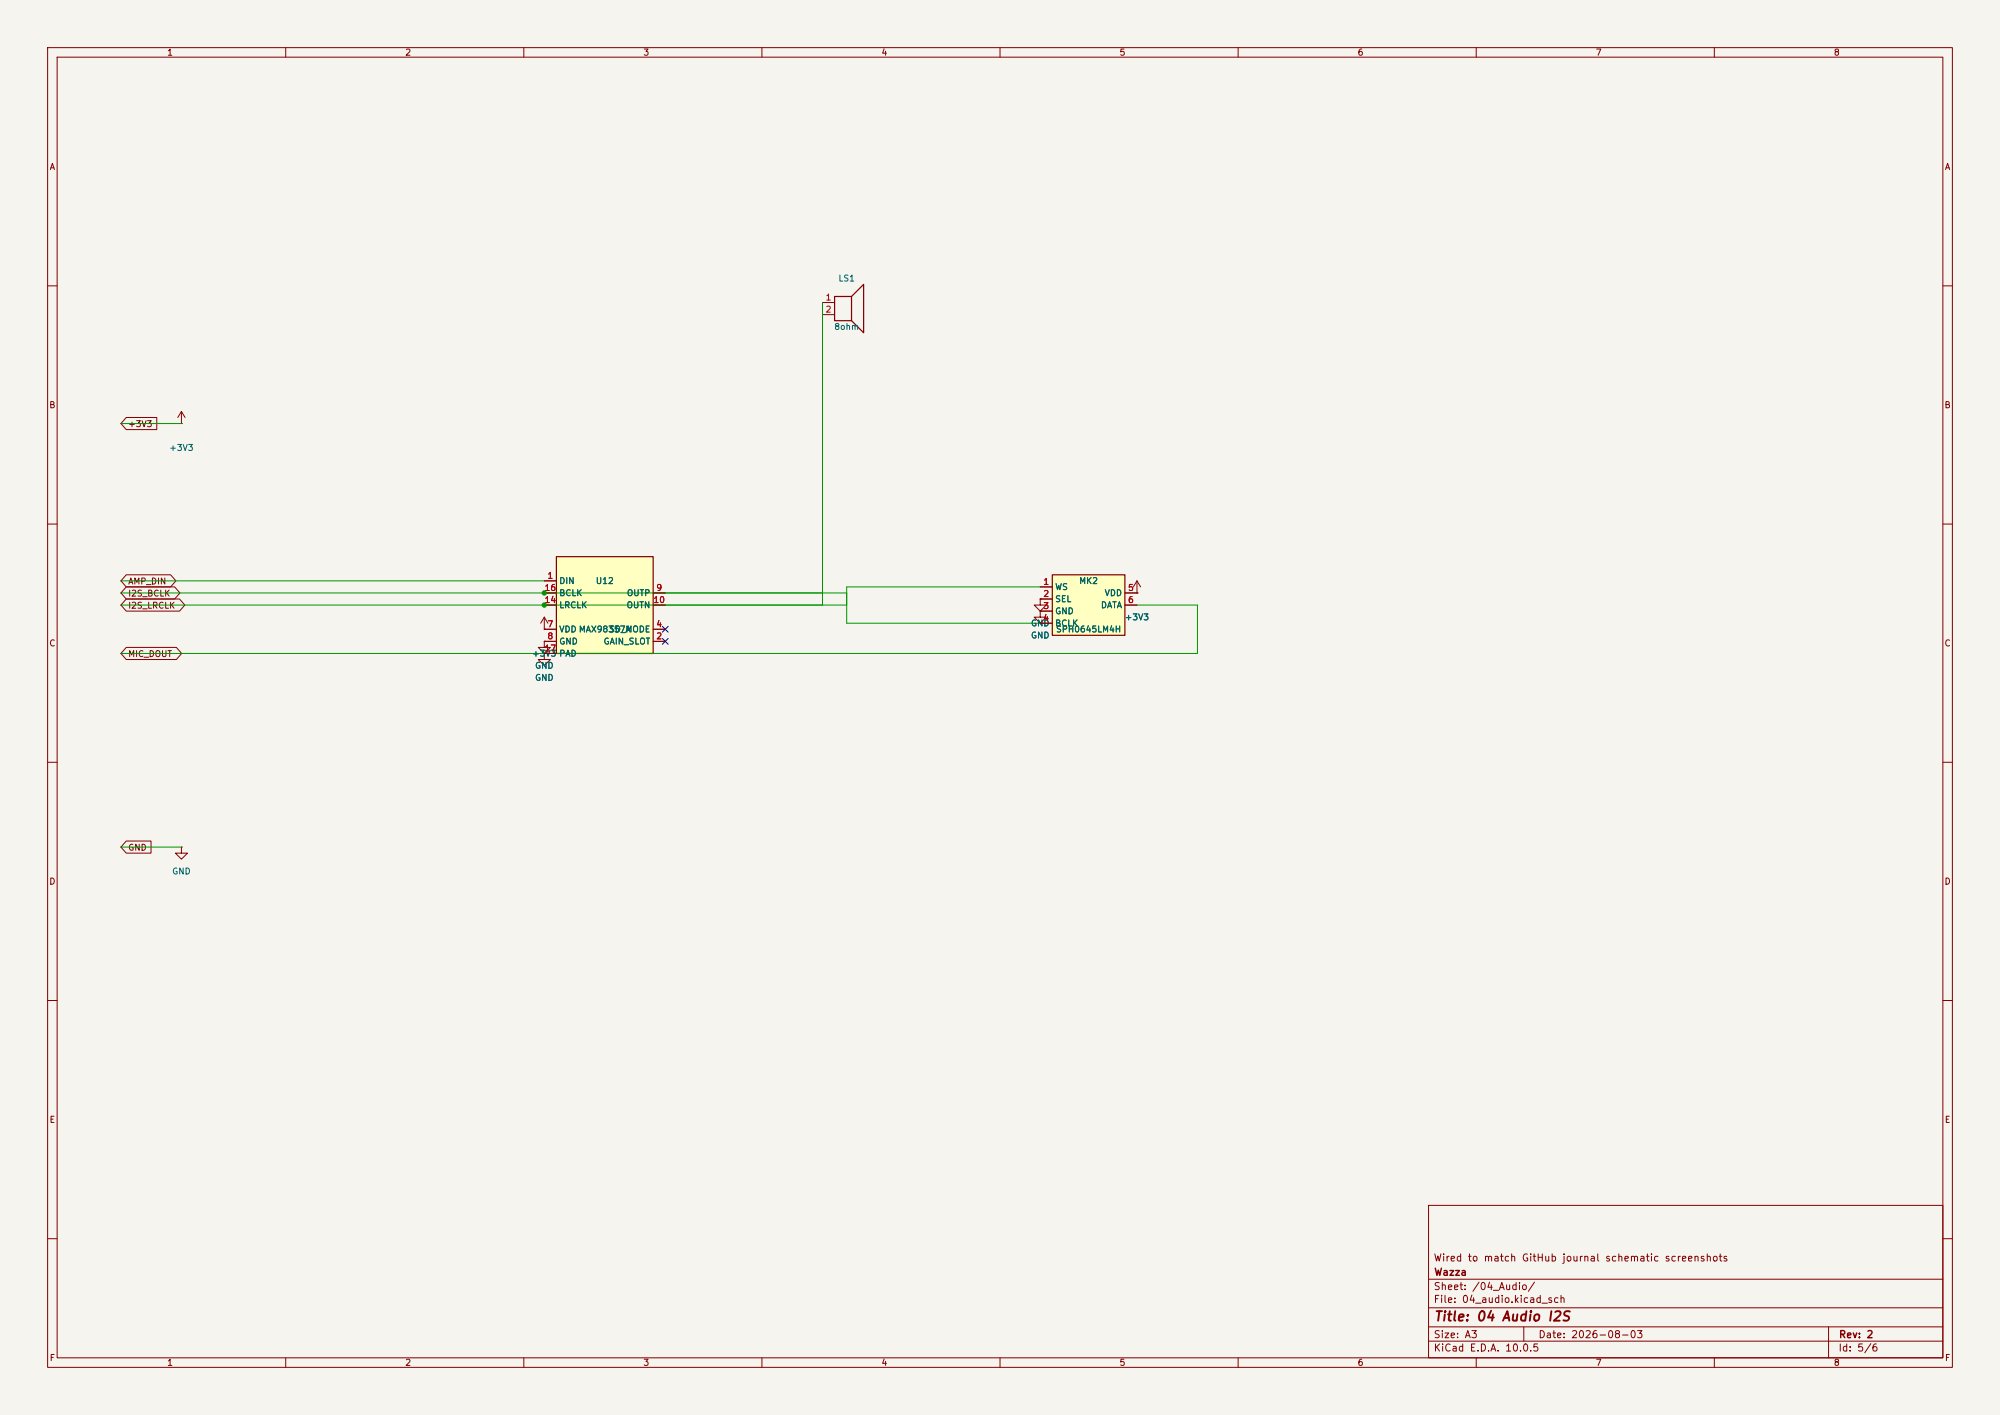
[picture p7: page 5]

Wired to match GitHub journal schematic screenshots
Wazza
Sheet: /04_Audio/
File: 04_audio.kicad_sch
Title: 04 Audio I2S

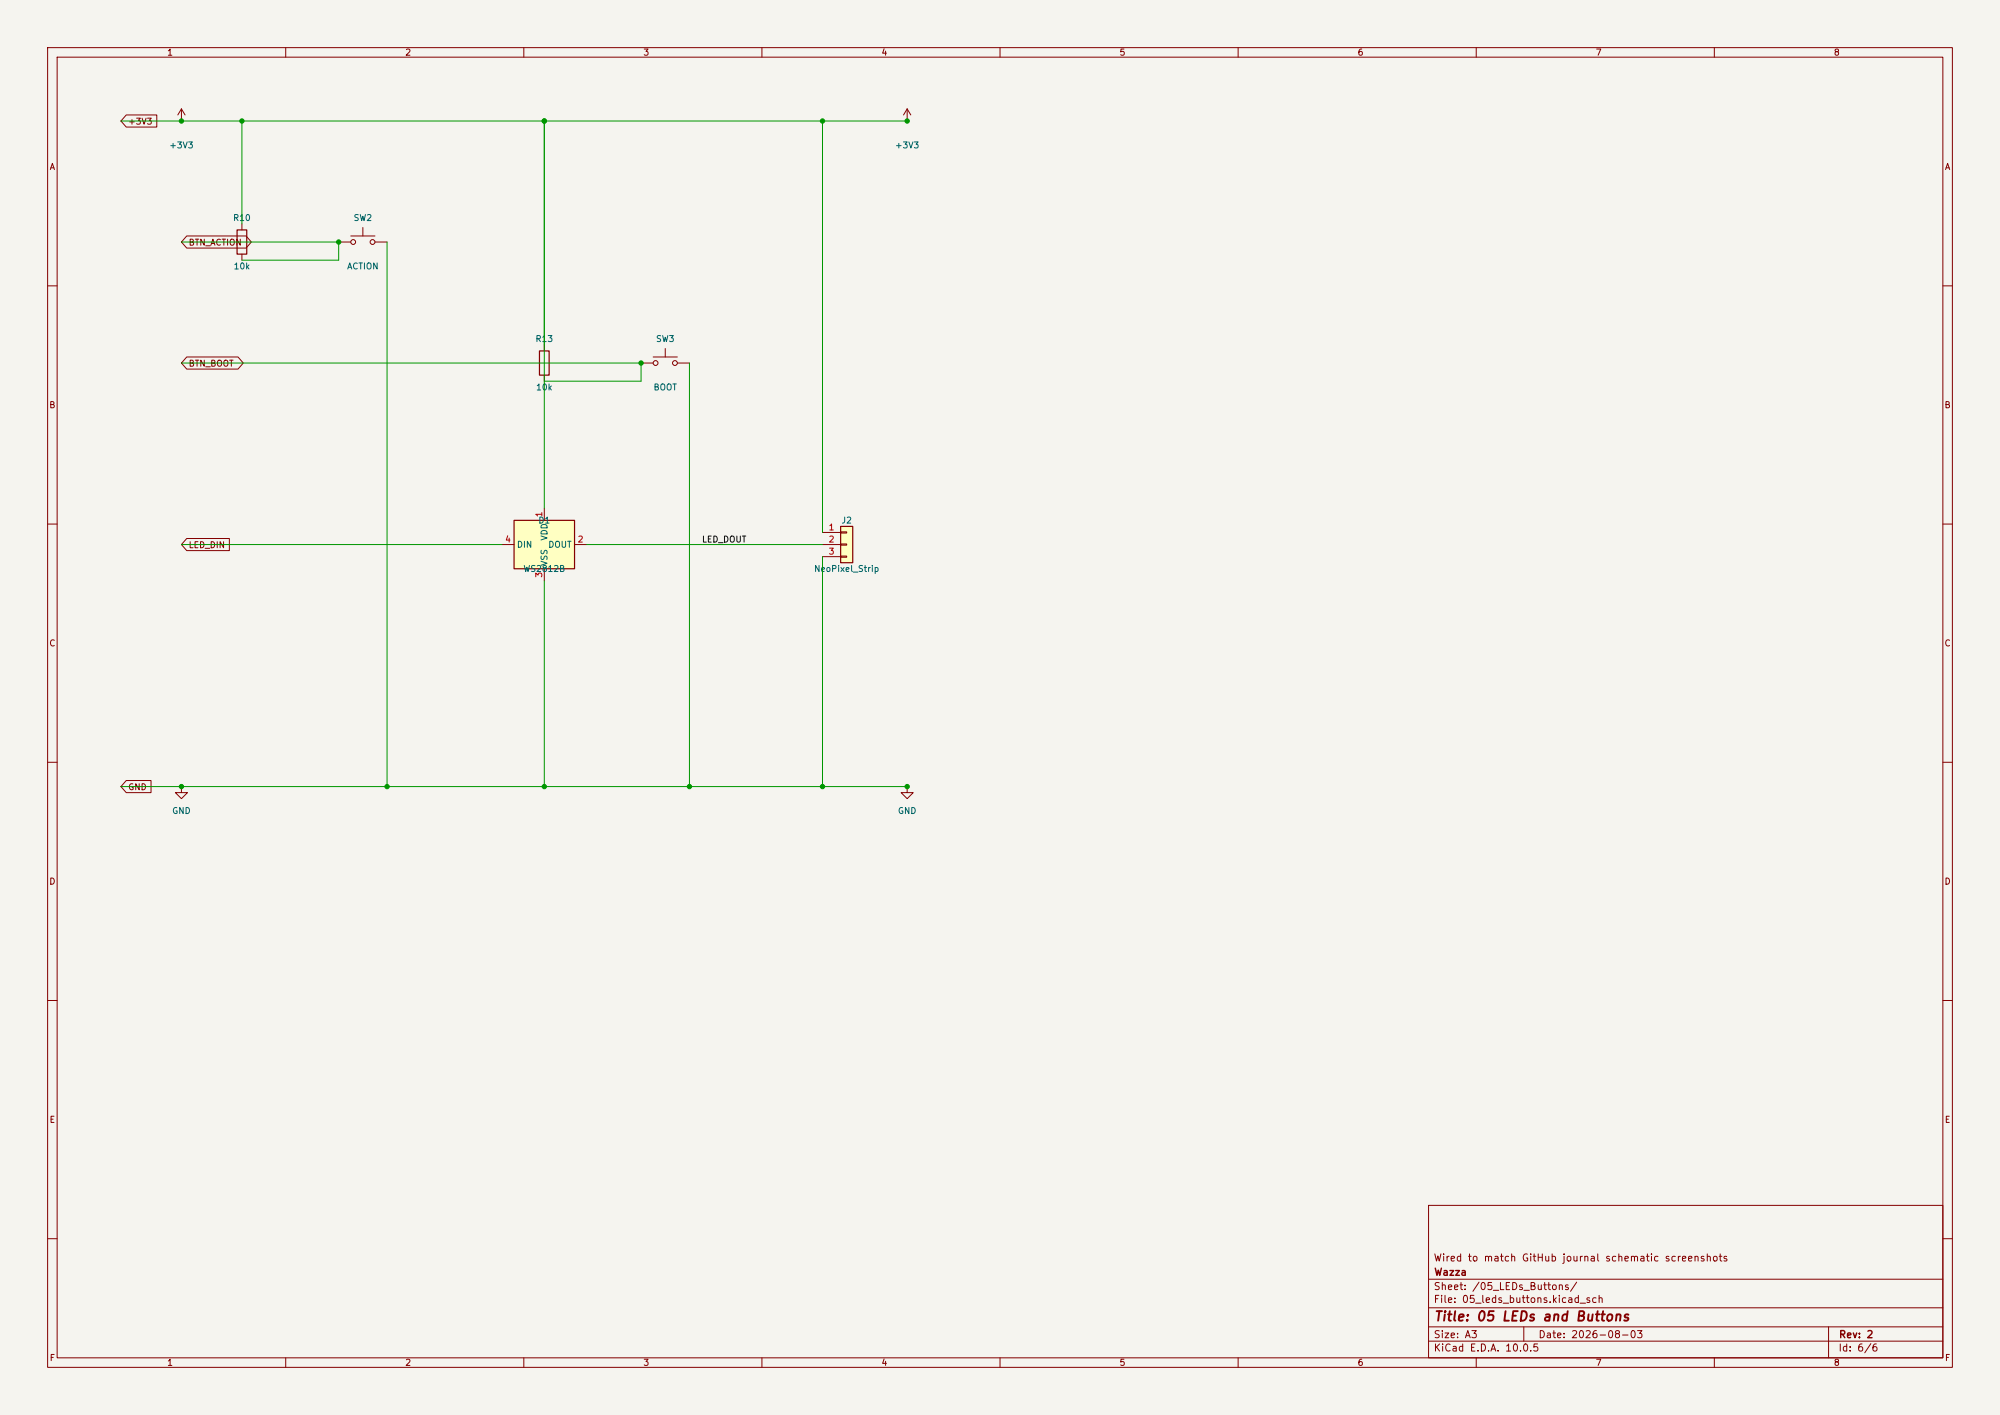
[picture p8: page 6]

Wired to match GitHub journal schematic screenshots
Wazza
Sheet: /05_LEDs_Buttons/
File: 05_leds_buttons.kicad_sch
Title: 05 LEDs and Buttons

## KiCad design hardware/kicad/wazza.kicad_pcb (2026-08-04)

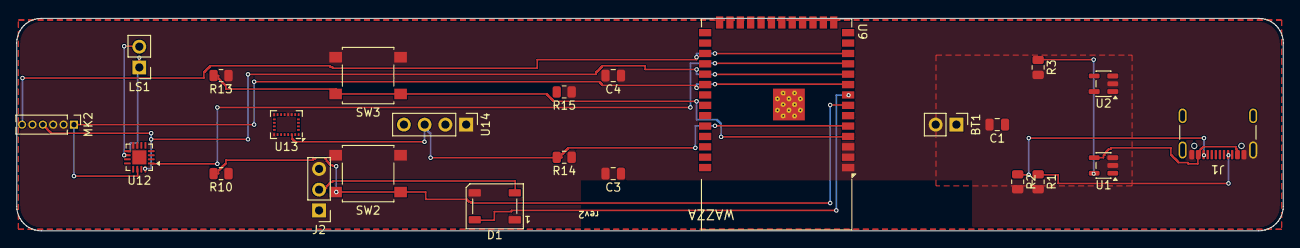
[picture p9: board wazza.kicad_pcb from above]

Board: 2 copper layers, 155.0 x 26.0 mm, 24 parts (0 on the bottom side), 19 nets.

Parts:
BT1: PinHeader_1x02_P2.54mm_Vertical
C1, C3, C4: C_0805_2012Metric
D1: LED_WS2812B_PLCC4_5.0x5.0mm_P3.2mm
J1: USB_C_Receptacle_GCT_USB4105-xx-A_16P_TopMnt_Hori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; USB_C_Receptacle_GCT_USB4105-xx-A_16P_TopMnt_Horizontal
J2: PinHeader_1x03_P2.54mm_Vertical
LS1: PinHeader_1x02_P2.54mm_Vertical
MK2: PinHeader_1x06_P1.27mm_Vertical
R1, R2, R3, R10, R13, R14, R15: R_0805_2012Metric
SW2, SW3: SW_SPST_B3S-1000
U1, U2: SOT-23-5
U9: ESP32-S3-WROOM-1
U12: QFN-16-1EP_3x3mm_P0.5mm_EP1.7x1.7mm
U13: LGA-24L_3x3.5mm_P0.43mm
U14: PinHeader_1x04_P2.54mm_Vertical

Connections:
+3V3: C1.1, C3.1, C4.1, D1.1, J2.1, MK2.5, R10.1, R13.1, R14.1, R15.1, U2.5, U9.2, U9.3, U12.7, U13.8, U13.13, U14.2
/05_LEDs_Buttons/LED_DOUT: D1.2, J2.2
AMP_DIN: U9.11, U12.1
BTN_ACTION: R10.2, SW2.1, U9.7
BTN_BOOT: R13.2, SW3.1, U9.4
GND: BT1.2, C1.2, C3.2, C4.2, D1.3, J1.A1, J1.A12, J1.B1, J1.B12, J1.SH, J2.3, MK2.2, MK2.3, R1.2, R2.2, R3.2, SW2.2, SW3.2, U1.2, U2.2, U9.1, U12.8, U12.17, U13.9, U13.18, U14.1
I2S_BCLK: MK2.4, U9.10, U12.16
I2S_LRCLK: MK2.1, U9.9, U12.14
LED_DIN: D1.4, U9.8
MIC_DOUT: MK2.6, U9.12
unnamed: BT1.1, U1.3, U2.1, U2.3
unnamed: J1.A5, R1.1
unnamed: J1.B5, R2.1
unnamed: R3.1, U1.5
unnamed: J1.A4, J1.A9, J1.B4, J1.B9, U1.4
unnamed: LS1.2, U12.10
unnamed: LS1.1, U12.9
SCL: R14.2, U9.5, U13.23, U14.3
SDA: R15.2, U9.6, U13.24, U14.4

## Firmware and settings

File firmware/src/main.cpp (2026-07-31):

#include <Arduinho.h>
#include <Wire.h>

#include "config.h"
#include "secrets.h"
#include "led_strip.h"
#include "imu_sensor.h"

static unsigned long lastTelemetryMs = 0;

void setup() {
    WandLog::begin(115200);
    WandLog::info("Wazza Setup Start");

    Wire.begin(PIN_I2C_SDA, PIN_I2C_SCL);
    Buttons::begin();
    LedStrip::begin();
    OledUi::begin();
    OledUi::showBoot("sensors...");
    ImuSensor::begin();
    GestureEnginer::begin();
    AudioIo::begin();

    NetClient::onCommand(CommandRouter::handle);
    NetClient::onConnection([](bool ok) {
        if (ok) LedStrip:: fill(0,30,0);
        else LedStrip::fill(30,0,0);
    });

    if (!NetClient::begin()) {
        LedStrip::fill(40,0,0);
    }
    else {
        LedStrip::fill(0,30,0);
        AudioIo::playBeep(987, 60);
    }

    WandLog::info("Wazza Setup Complete.");

}

void loop(){
    NetClient::loop();
    Buttons::poll();
    AudioIo::loop();

    if (buttons::actionPressedEdge()) {
        NetClient::sendEvent("button", "action");
        LedStrip::flash(200, 80, 255, 1, 80);
    }
    if (Buttons::bootPressedEdge() {
        NetClient::sendEvent("button", "boot");
    }

    ImuSample sample;
    If(ImuSensor::read(sample)) {
        GestureType g = GestureEngine::update(sample, Buttons::actionHeld());
        if (g != GestureType::None) {
            const char *name = gestureName(g);
            NetClient::sendEvent("gesture", name);
            LedStrip::flash(160, 40, 255, 1, 70);
            WandLog::info("gesture &s", name);
        }

        unsigned long now = millis(); 
        if (TELEMETRY_INTERVAL_MS > 0 &&
            now - lastTelemtryMs >= TELEMETRY_INTERVAL_MS &&
            NetClient::connected()) {
            lastTelemetryMs = now;
            NetClient::sendImu(sample.ax, sample.ay, sample.az, sample.gx, sample.gy, sample.gz);
            }
    }

    delay(1000 / GESTURE_SAMPLE_HZ);
}

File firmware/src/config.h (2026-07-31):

#pragma once

// I2C SDA and SCL. (MPU-6050 & OLED)
#define PIN_I2C_SDA 5
#define PIN_I2C_SCL 4

// WS2812 LEDs.
#define PIN_WS2812_DIN 18
#define NUM_LEDS 16
#define LED_BRIGHTNESS 80

// Buttons.
#define PIN_BTN_BOOT 0
#define PIN_BTN_ACTION 8
#define BTN_ACTIVE_HIGH 0

// I2S pins. (Audio)
#define PIN_I2S_BCLK 26
#define PIN_I2S_LRCLK 21
#define PIN_I2S_AMP_DIN 33
#define PIN_I2S_MIC_DOUT 34

// OLED display.
#define OLED_WIDTH 128
#define OLED_HEIGHT 32
#define OLED_I2C_ADDRESS 0x3C

// Gestures (Motion detection thresholds and timing)
#define PIN_GESTURE_SAMPLE_HZ 100
#define FLICK_THRESHOLD 12.0f
#define FLICK_HARD_THRESHOLD 18.0f
#define SWIPE_THRESHOLD 5.0f
#define SHAKE_THRESHOLD 15.0f
#define CIRCLE_GYRO_MIN 4.0f
#define GESTURE_COOLDOWN_MS 500
#define HOLD_MS 900

// Telemetry / Net
#define TELEMETRY_INTERVAL_MS 100
#define WS_RECONNECT_MS 2000
#define WIFI_CONNECT_TIMEOUT_MS 20000

// Features
#define ENABLE_AUDIO 1
#define ENABLE_OLED 1
#define ENABLE_LEDS 1
#define ENABLE_IMU 1

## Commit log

2026-06-29 Add journal entry for schematic completion
    Documented the completion of the schematic with design decisions, architecture, and next steps.
2026-06-29 Add schematic image to README
2026-06-29 Update schematic completion entry with time spent
    Added time spent to the schematic completion entry.
2026-06-29 Document Day 6 progress on PCB organization
    Added Day 6 reflection on PCB organization and progress.
2026-06-29 Document progress on PCB organization
    Added reflections on the PCB organization process.
2026-06-29 Update README with new schematic and future enhancements
    Added a new schematic image and outlined potential future enhancements for the project.
2026-06-29 Fix major PCB layout errors and improve schematic
    Corrected wiring paths for resistors R4 and R5 on the PCB layout, fixing a major error that affected the communication loop. Made additional adjustments to address widespread design flaws in the schematic.
2026-06-30 Update journal with Day 2 PCB progress
    Document progress on PCB creation, including challenges with wiring and plans for future improvements.
2026-06-30 Revise Journal Day to 6/29/26 and update content
    Updated journal entry date and details about PCB progress.
2026-06-30 Document schematic rewire and ESP32 module update
    Updated the journal with progress on schematic rewiring and ESP32 module clarification.
2026-06-30 Document schematic rewire progress in journal
    Updated the journal with details on schematic rewiring and ESP32-S3 Mini usage.
2026-06-30 Revise journal entries for PCB layout progress
    Updated journal entries to reflect progress on PCB layout and troubleshooting steps taken with the ESP32 module. Added sections on design decisions, architecture, and next steps for the project.
2026-07-01 Finalize schematic overhaul and subsystem integration
    Completed schematic overhaul, migrating to a modular design with hierarchical sheets and integrating OLED and audio interfaces. Verified core component corrections and ensured all subsystems are connected to the ESP32-S3 Mini.
2026-07-03 Revise project status and add PCB organization details
    Updated project status and added new PCB organization section.
2026-07-04 Document PCB routing progress and add images
    Added updates on PCB routing progress with images.
2026-07-08 Document completion of PCB routing and designs
    Added completion section for PCB routing and designs.
2026-07-08 Add schematic images to README
    Added multiple schematic images to the README file.
2026-07-08 Fix typo in components list and enhance power system description
    Corrected a typo in the list of components and added a description about the power system functionality.
2026-07-11 Initial Wazza scaffold: ESP32 firmware, Python backend, web dashboard
2026-07-11 Update README with new images and enhancements section
    Added two new images to the PCB section and expanded the Future Enhancements section with potential improvements.
2026-07-11 Wire LLM into backend with OpenAI/Ollama support and dashboard prompt panel
2026-07-11 Revise journal entries for clarity and accuracy
    Updated journal entries to reflect changes in schematic rewiring, PCB organization, and project milestones. Enhanced clarity and corrected errors in component descriptions and layout processes.
2026-07-11 Add BOM with part links
2026-07-11 Fix grammar and clarity in BOM.md notes
2026-07-11 Format BOM as lists
2026-07-11 Revise BOM title and description for clarity
    Updated title and description for clarity.
2026-07-31 Document progress and lapsed days in journal
    Added notes about lapsed days and detailed progress on schematic and PCB layout, including fixes and rewiring.
2026-08-03 Revise Future Enhancements and add CAD STEP file link
    Updated the Future Enhancements section with specific potential improvements and added a CAD STEP file reference.
2026-08-03 Add KiCad PCB, Gerbers, enclosure STEP, and assembly/wiring docs.
    Recreates the journal PCB placement in a 155x26mm outline sized for the Wand3 STEP cavity, and ships fab outputs plus schematic PDF.
    [01_power.kicad_sch, 02_mcu.kicad_sch, 03_sensors.kicad_sch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]
2026-08-04 Update routed KiCad PCB, Gerbers, STEP, and assembly/wiring docs.
    Refreshes fab outputs from the autorouted board and documents build/fit notes for resubmission.
    [wazza-B_Cu.gbl, wazza-B_Mask.gbs, wazza-B_Paste.gbp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]
2026-08-04 Update README with additional PCB images and CAD file
    Added new images and a CAD STEP file reference to the PCB section.
